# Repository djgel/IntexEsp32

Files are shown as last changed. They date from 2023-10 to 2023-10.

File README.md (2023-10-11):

# Intex® PureSpa ESP32 control Board with Home Automation

**Control your PureSpa over MQTT for 28462, 28458 & 28457, 28561

This  software is user for hardware IntexESP32HW and used with Smart Home (optimized for [Jeedom](www.jeedom.com) & [Home Assistant](https://www.home-assistant.io)).

Codes has partial copy / inspiration of [Yogui79/IntexPureSpa] (https://github.com/Yogui79/IntexPureSpa/blob/main/README.md#hardware-to-you-need)

## Pictures & Videos
-------
- [Video - Home Assistant - Screen Recording ](https://youtu.be/5Z1keongL40)

## Hardware to you need

-   **ESP32 Dev Kit 38Pin**  (Microcontroller) -  [amazon.de](https://amzn.to/3uoa2y4) or [amazon.fr](https://amzn.to/2RvXbLn)]
-   "[**Esp32PureSpa**] (Hardware/)" Board to make! (in Developed)

## Software to you need

-   [**Arduino IDE**](https://www.arduino.cc/en/software)
-   **Install the “[ESP32 Dev Kit C 38pin](https://www.silabs.com/developers/usb-to-uart-bridge-vcp-drivers)” ** (V1 boards not  work)
-   **Install ESP32 Board for  Arduino IDE (verssion 1.0.6)  ->  [Screenshot](Docs/Image/Board-Screenshot-IDE.PNG). **
-   **Install the following libraries**  (use the Arduino Library Manager)
    -   EspMQTTClient
    -   arduino-timer
    -   WiFi (comming with Board Driver in Arduino IDE)
    -   ESPmDNS (comming with Board Driver in Arduino IDE)
    -   ArduinoOTA
-   **You need a MQTT broker**  (e.g. Mosquitto Broker)

## PureSpa Software
Now you can [Download](src/Spa/) the PureSpa code change it to your settings and upload it to your ESP or Arduino

## MQTT communication protocol

**Write your WIFI settings in this lines**

```
const char* Myssid = "YourSSID";
const char* Mypassword = "YourPassword";
```

----------

**Write your MQTT settings in this lines**

```
"YourMQTT-Broker-IP", 	  // MQTT Broker server ip
"NameMQTTBroker",        // Can be omitted if not needed
"PasswordMQTTBroker",   // Can be omitted if not needed
"IntexSpa",            // Client name that uniquely identif your device. Don't change the name!
 1883                 // The MQTT port, default to 1883. this line can be omitted
```

----------

**MQTT topic & payload**

-   Topic is the path to communtions over MQTT:  
    e.g.:  _**IntexSpa/Cmd Power on off**_
-   Payload is the command 

| Description | Topic String | Payload | Payload | Only Status |
|---|---|---|---|---|
| **Power** | IntexSpa/Cmd Power on off | ON=1 | OFF=0 | - |
| **Water Filter** | IntexSpa/Cmd water filter on off | ON=1 | OFF=0 | - |
| **Water Filter Timer** | IntexSpa/Cmd water filter time | hours=2,4,6 | - | - |
| **Bubble** | IntexSpa/Cmd bubble on off | ON=1 | OFF=0 | - |
| **Heater** | IntexSpa/Cmd heater on off | ON=1 | OFF=0 | - |
| **Change Farenheit/Celsius** | IntexSpa/Cmd Farenheit Celsius | F=1 | C=0 | - |
| **Decrease the Temp.** | IntexSpa/Cmd decrease | UP=1 | - | - |
| **Increase the Temp.** | IntexSpa/Cmd increase | Down=1  | - | -  
| **ESP Reset** | IntexSpa/Cmd Reset ESP | reset | - | - |  
| **Command Setpoint of Temp.** | IntexSpa/Cmd Temperature Setpoint| "set a number"  | - | -
| **Heater Status** | IntexSpa/heater state | standby=1 & ON=2  | OFF=0 | Yes
| **Status Setpoint Temp.** | IntexSpa/Temperature Setpoint | - | - | Yes
| **Send Actual Temp 01.** | IntexSpa/Actual Temperature01 | - | - | Yes |
| **Send Actual Temp 02.** | IntexSpa/Actual Temperature02 | - | - | Yes |out
| **Send Actual Flow.** | IntexSpa/Actual Flow | - | - | Yes |
| **Send Error Message** | IntexSpa/Error Number | - | - | Yes |
| **Status Power on** | IntexSpa/Power on | - | - | Yes |  
| **Status Bubble on** | IntexSpa/Bubble on | - | - | Yes |  
| **Status Heater on** | IntexSpa/heater on | - | - | Yes |  
| **Status Filter on** | IntexSpa/filter on | - | - | Yes |
| **Status Filter Timer** | IntexSpa/filter setup time | - | - | Yes | 
| **Water Jet** |  IntexSpa/Cmd water jet on off | ON=1 | OFF=0 | - |
| **Sanitizer** | IntexSpa/Cmd sanitizer on off | ON=1 | OFF=0 | - |
| **Status Water Jet** | IntexSpa/Water jet on | - | - | Yes |
| **Sanitizer Timer** | IntexSpa/Cmd Sanitizer time | hours=3,5,8 | -  | - |
| **Status Sanitizer** | IntexSpa/Sanitizer on | - | - | Yes |
| **Status Sanitizer Timer** | IntexSpa/Sanitizer setup time | - | - | Yes |

## Debugging

You can debug on Arduino IDE with serial print on  **baud rate: 115200**

Options to debug  
_Uncomment to debug_  

	//#define DEBUG_RECIEVED_DATA
	//#define DEBUG_SEARCH_CHANNEL
	//#define DEBUG_SEND_COMMAND
	//#define DEBUG_PUMP_DATA
	//#define DEBUG_CONTROLER_DATA
	//#define DEBUG_CONFIG
	//#define DEBUG_MQTT
	//#define DEBUG_SEND_VALUE_TO_HOME_AUTOMATION_SW

## OTA update

You can use OTA update (wireless) via Arduino IDE after the first upload via USB.  [Screenshot](Docs/Image/Screenshot-OTA.PNG)

## Home Assistant
Is a powerful open source home automation software. [www.home-assistant.io](https://www.home-assistant.io)

You can use it as you want, I'll show you an example of a part of the files configuration.yaml and automations.yaml

**Screenshot & Video:**
1. [OFF - Whrilpool Screenshot](Docs/Image/1.HomeAssistant-OFF_Screenshot.jpg) 
2. [ON - Whrilpool Screenshot](Docs/Image/2.HomeAssistant-ON_Screenshot.jpg)
3. [Help/Infos/Reset Screenshot](Docs/Image/3.HomeAssistant-Help-Infos_Screenshot.jpg)
4. [Heat Timer](Docs/Image/4.HomeAssistant-Timer_Screenshot.jpg)
5. [Push-notification Screenshot](Docs/Image/5.HomeAssistant-Push-notification_Screenshot.jpg)
6. [Video - Screen Recording ](https://youtu.be/5Z1keongL40)

**Config of Home Assistant:** 
- [**configuration.yaml**](src/HomeAutomation/HomeAssistant/configuration.yaml)
   - Define the switches and sensors with MQTT Topics and Payload.

- [**automations.yaml**](src/HomeAutomation/HomeAssistant/automations.yaml) **(optional)**

  - All your automation settings such as push-notification on your mobile phone.

## Jeedom 

Is a powerful and innovative open source home automation software. [www.jeedom.com](https://jeedom.com/)

**Screenshot & Video:**
1. [Screenshot dashboard view](Docs/Image/10.Jeedom-Dashboard.png)
2. [Wiring video](https://www.youtube.com/watch?v=50lxF08o_vo) thanks [@Dim](https://github.com/jeedom-help-Dim-Ant)
3. Configuration video **comming soon**.

**Config of Jeedom:** 

Template for the MQTT topics are available inside the beta version from the jeedom plugin jMQTT

**On jeedom Community thread:** 

you can found some information/help (in french) on the [Jeedom Community thread](https://community.jeedom.com/t/intex-purespa-avec-commande-sans-fils/59334)

## The official Intex® PureSpa instructions

| Articel No. | English  | German |
|---|---|---|
| 28462, 28458 & 28457, 28561 | [Download](Docs/28462-28458_344IO_202_EN_.pdf) | [Download](Docs/28462_28458_344IO_2020_DE.pdf) |

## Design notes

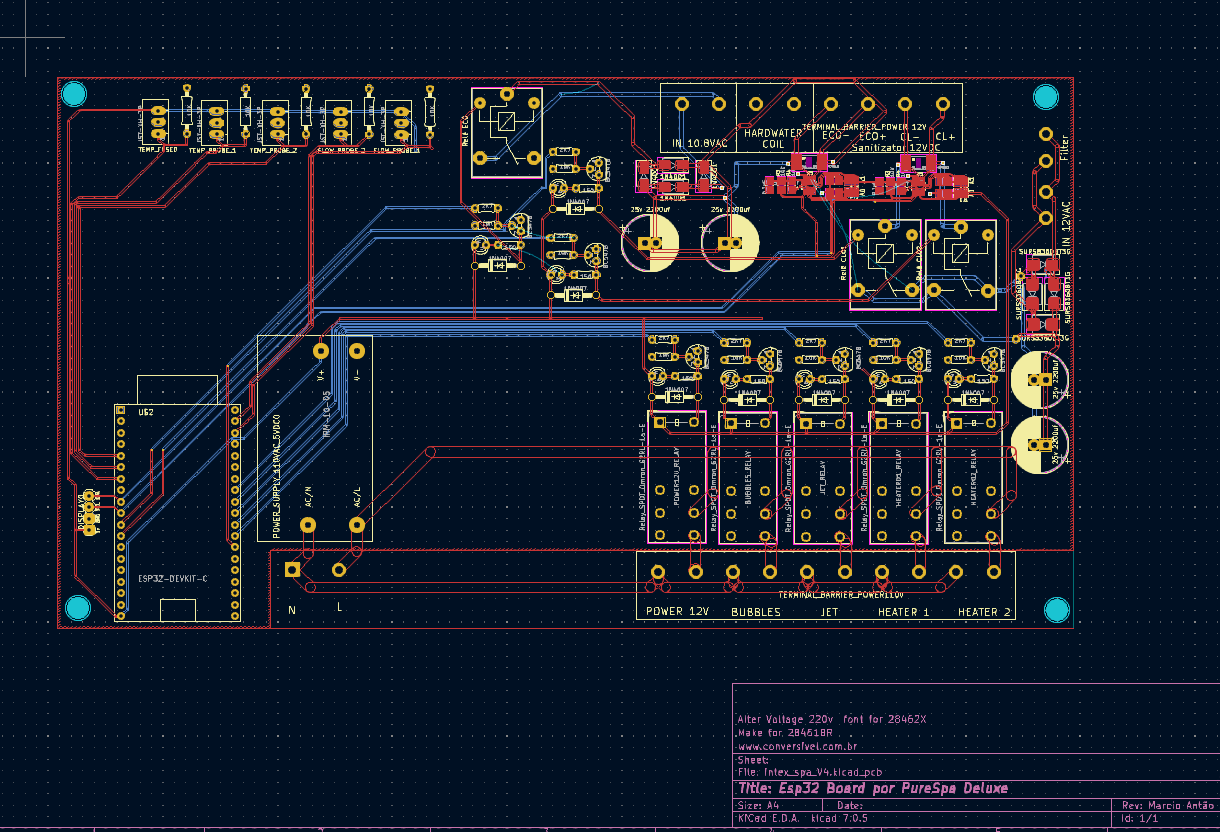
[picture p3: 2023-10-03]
img/BoardKicad.png

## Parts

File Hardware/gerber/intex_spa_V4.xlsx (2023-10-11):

Id | Designador | Footprint | Quantidade | DesignaÃ§Ã£o | Fornecedor e referÃªncia
1 | D8,D13,D15,D14,D9,D10,D11,D12 | DO41-10 | 8 | 1N4007
2 | FLOW_PROBE_2,FLOW_PROBE_1,TEMP_FUSED,TEMP_PROBE_1,TEMP_PROBE_2 | JST-XH-03-PACKAGE-LONG-PAD | 5 | JST-XH-3P
4 | R21,R16,R25,R24,R20,R22,R19,R17 | 805 | 8 | 10K
5 | C4,C1,C3,C2 | CP_Radial_D12.5mm_P2.50mm | 4 | CP_Radial_D12.5mm_P2.50mm
6 | S1 | SW_DIP_SPSTx01_Slide_6.7x4.1mm_W7.62mm_P2.54mm_LowProfile | 1 | SW_DIP_SPSTx01_Slide_6.7x4.1mm_W7.62mm_P2.54mm_LowProfile
7 | U1,U2 | SOT23-8 | 2 | INA219BIDCNT
9 | R34,R11,R31,R28,R25,R37,R14,R8 | 0204_5 | 8 | 10K
10 | D4,D2,D3,D1 | D_SMB | 4 | SURS8360BT3G
11 | RelÃª ECO,RelÃª CL02,RelÃª CL01 | Relay_SPDT_SANYOU_SRD_Series_Form_C | 3 | Relay_SPDT_SANYOU_SRD_Series_Form_C
12 | T_HEATER2_RELAY,T_BUBBLES_RELAY,T_RELAY_CL2,T_PUMP_RELAY0,T__HEATER1_RELAY,T_PUMP_RELAY1,T_RELAY_CL1,T_RELAY_ECO | TO92 | 8 | BC547B
13 | R9,R12,R38,R15,R32,R29,R35,R26 | 0204_5 | 8 | 150
14 | D6,D5,D8,D7 | D_SMA | 4 | 1N4001
15 | R3,R4,R1,R6,R5 | 0207_10 | 5 | 10K
16 | LED_HEATER1_RELAY,LED_RELAY_CL2,LED_RELAY_CL1,LED_HEATER2_RELAY,PUMP0,LED_BUBBLES_RELAY,LED_RELAY_ECO,JET0 | LED3MM | 8
18 | DISPLAY0 | 1X04 | 1 | 4 PINS CONNECTOR
19 | C6,C5 | 805 | 2 | 0.1ÂµF
20 | BUBBLES_RELAY,HEATER02_RELAY,POWER12V_RELAY,HEATER01_RELAY,JET_RELAY | Relay_SPDT_Omron_G2RL-1-E | 5 | Relay_SPDT_Omron_G2RL-1a-E
21 | TERMINAL_BARRIER_POWER 12V | 4PCV-04-006 | 1 | 4PCV-04-006
22 | R30,R10,R27,R36,R7,R33,R13,R24 | 0204_5 | 8 | 2K7
23 | R18,R23 | 2512 | 2 | 0.1/1% (PT2512FK-070R1L)
24 | POWER_SUPPLY_110VAC_5VDC0 | IRM_05_10 | 1 | IRM-10-05
25 | TERMINAL_BARRIER_POWER110v | 4PCV-10-006 | 1 | 4PCV-10-006
26 | TERMINAL_BARRIER_POWER 12V | 4PCV-08-006 | 1 | 4PCV-08-006

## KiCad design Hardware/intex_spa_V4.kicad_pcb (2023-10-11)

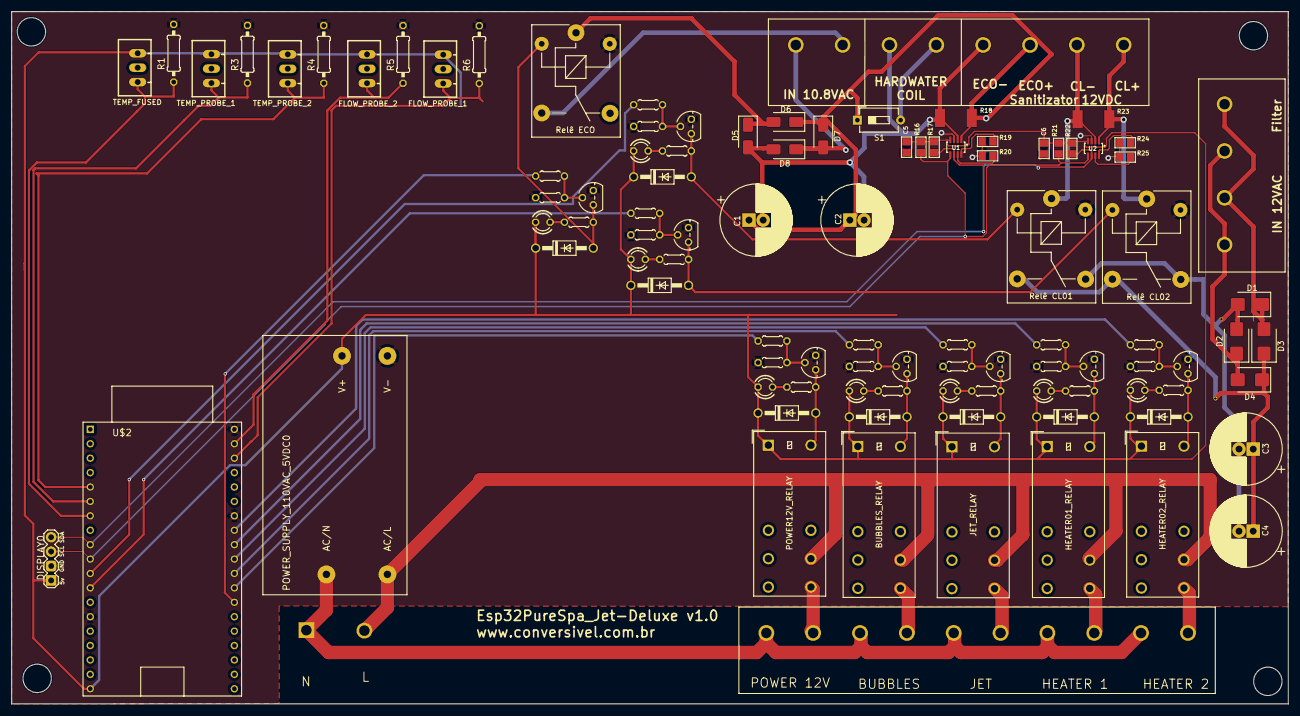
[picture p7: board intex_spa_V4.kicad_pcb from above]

Board: 2 copper layers, 225.0 x 122.0 mm, 103 parts (0 on the bottom side), 59 nets.

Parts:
@HOLE0, @HOLE1, @HOLE2, @HOLE3: (no value)
BUBBLES_RELAY: Relay_SPDT_Omron_G2RL-1a-E; Relay_SPDT_Omron_G2RL-1-E
C1, C2, C3, C4: CP_Radial_D12.5mm_P2.50mm
C5, C6: 0.1µF; 0805
D1, D2, D3, D4: SURS8360BT3G; D_SMB
D5, D6, D7, D8#2: 1N4001; D_SMA
D8, D9, D10, D11, D12, D13, D14, D15: 1N4007; DO41-10
DISPLAY0: 4 PINS CONNECTOR; 1X04
FLOW_PROBE_1, FLOW_PROBE_2: JST-XH-3P; JST-XH-03-PACKAGE-LONG-PAD
HEATER01_RELAY, HEATER02_RELAY: Relay_SPDT_Omron_G2RL-1a-E; Relay_SPDT_Omron_G2RL-1-E
JET0: LED3MM
JET_RELAY: Relay_SPDT_Omron_G2RL-1a-E; Relay_SPDT_Omron_G2RL-1-E
LED1: LED3MM
LED_BUBBLES_RELAY: LED3MM
LED_HEATER1_RELAY, LED_HEATER2_RELAY: LED3MM
LED_RELAY_CL1, LED_RELAY_CL2: LED3MM
POWER12V_RELAY: Relay_SPDT_Omron_G2RL-1a-E; Relay_SPDT_Omron_G2RL-1-E
POWER_SUPPLY_110VAC_5VDC0: IRM-10-05; IRM_05_10
PUMP0: LED3MM
R1, R3, R4, R5, R6: 10K; 0207_10
R7, R10, R13, R24#2, R27, R30, R33, R36: 2K7; 0204_5
R8, R11, R14, R25#2, R28, R31, R34, R37: 10K; 0204_5
R9, R12, R15, R26, R29, R32, R35, R38: 150; 0204_5
R16, R17, R19, R20, R21, R22, R24, R25: 10K; 0805
R18, R23: 0.1/1% (PT2512FK-070R1L); 2512
Relê CL01, Relê CL02: Relay_SPDT_SANYOU_SRD_Series_Form_C
Relê ECO: Relay_SPDT_SANYOU_SRD_Series_Form_C
S1: SW_DIP_SPSTx01_Slide_6.7x4.1mm_W7.62mm_P2.54mm_Lo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; SW_DIP_SPSTx01_Slide_6.7x4.1mm_W7.62mm_P2.54mm_LowProfile
TEMP_FUSED: JST-XH-3P; JST-XH-03-PACKAGE-LONG-PAD
TEMP_PROBE_1, TEMP_PROBE_2: JST-XH-3P; JST-XH-03-PACKAGE-LONG-PAD
TERMINAL_BARRIER_POWER110v: 4PCV-10-006
TERMINAL_BARRIER_POWER 12V: 4PCV-04-006
TERMINAL_BARRIER_POWER 12V#2: 4PCV-08-006
T_BUBBLES_RELAY: BC547B; TO92
T_HEATER2_RELAY: BC547B; TO92
T_PUMP_RELAY0, T_PUMP_RELAY1: BC547B; TO92
T_RELAY_CL1, T_RELAY_CL2: BC547B; TO92
T_RELAY_ECO: BC547B; TO92
T__HEATER1_RELAY: BC547B; TO92
U1, U2: INA219BIDCNT; SOT23-8
U$2: ESP32-DEVKIT-C

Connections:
10.8VAC+: D5.1, D6.2, Relê ECO.1, Relê ECO.3, TERMINAL_BARRIER_POWER 12V#2.I2
10.8VAC_N: D7.2, D8#2.1, TERMINAL_BARRIER_POWER 12V#2.I1
12VAC+: D1.1, D3.2, TERMINAL_BARRIER_POWER 12V.I2, TERMINAL_BARRIER_POWER 12V.I4
12VAC_N: D2.1, D4.2, TERMINAL_BARRIER_POWER 12V.I1, TERMINAL_BARRIER_POWER 12V.I3
12VDC+: C1.1, C2.1, C3.1, C4.1, D3.1, D4.1, D6.1, D7.1, R18.2, Relê CL01.3, Relê CL02.3, S1.1, S1.2, TERMINAL_BARRIER_POWER 12V#2.I4, TERMINAL_BARRIER_POWER 12V#2.I6, U1.1
12VDC-: C1.2, C2.2, C3.2, C4.2, D1.2, D2.2, D5.2, D8#2.2, R18.1, Relê CL01.4, Relê CL02.4, TERMINAL_BARRIER_POWER 12V#2.I3, TERMINAL_BARRIER_POWER 12V#2.I5, U1.2
12VDC_CL: R23.1, R23.2, Relê CL01.1, Relê CL02.1, TERMINAL_BARRIER_POWER 12V#2.I7, TERMINAL_BARRIER_POWER 12V#2.I8, U2.1, U2.2
+5V: BUBBLES_RELAY.A1, C5.1, C6.1, D8.C, D9.C, D10.C, D11.C, D12.C, D13.C, D14.C, D15.C, DISPLAY0.1, FLOW_PROBE_1.3, FLOW_PROBE_2.3, HEATER01_RELAY.A1, HEATER02_RELAY.A1, JET0.A, JET_RELAY.A1, LED1.A, LED_BUBBLES_RELAY.A, LED_HEATER1_RELAY.A, LED_HEATER2_RELAY.A, LED_RELAY_CL1.A, LED_RELAY_CL2.A, POWER12V_RELAY.A1, POWER_SUPPLY_110VAC_5VDC0.V+, PUMP0.A, R16.2, R17.2, R21.2, R22.2, TEMP_FUSED.3, TEMP_PROBE_1.3, TEMP_PROBE_2.3, U1.4, U2.4, U$2.5V
A_BUBBLES: BUBBLES_RELAY.A2, D12.A, R29.2, T_BUBBLES_RELAY.3
A_CL_R01: D9.A, R15.2, Relê CL01.2, T_RELAY_CL1.3
A_CL_R02: D10.A, R12.2, Relê CL02.2, T_RELAY_CL2.3
A_ECO: D8.A, R9.2, Relê ECO.2, T_RELAY_ECO.3
A_HEATER_01: D14.A, HEATER01_RELAY.A2, R35.2, T__HEATER1_RELAY.3
A_HEATER_02: D15.A, HEATER02_RELAY.A2, R38.2, T_HEATER2_RELAY.3
A_JET: D13.A, JET_RELAY.A2, R32.2, T_PUMP_RELAY1.3
A_PUMP: D11.A, POWER12V_RELAY.A2, R26.2, T_PUMP_RELAY0.3
GND: C5.2, C6.2, DISPLAY0.2, POWER_SUPPLY_110VAC_5VDC0.V-, R1.2, R3.2, R4.2, R5.2, R6.2, R8.2, R11.2, R14.2, R19.1, R20.1, R24.1, R25.1, R25#2.2, R28.2, R31.2, R34.2, R37.2, Relê CL01.5, Relê CL02.5, Relê ECO.5, T_BUBBLES_RELAY.1, T_HEATER2_RELAY.1, T_PUMP_RELAY0.1, T_PUMP_RELAY1.1, T_RELAY_CL1.1, T_RELAY_CL2.1, T_RELAY_ECO.1, T__HEATER1_RELAY.1, U1.3, U2.3, U$2.GND, U$2.GND2, U$2.GND3
I1_ELT1: R20.2, U1.7
I1_ELT2: R25.2, U2.7
I2_ELT1: R19.2, U1.8
I2_ELT2: R24.2, U2.8
LEAD: BUBBLES_RELAY.11, HEATER01_RELAY.11, HEATER02_RELAY.11, JET_RELAY.11, POWER12V_RELAY.11, POWER_SUPPLY_110VAC_5VDC0.AC/L
LEAD_BUBBLES: BUBBLES_RELAY.14, TERMINAL_BARRIER_POWER110v.I4
LEAD_HEATER_1: HEATER01_RELAY.14, TERMINAL_BARRIER_POWER110v.I8
LEAD_HEATER_2: HEATER02_RELAY.14, TERMINAL_BARRIER_POWER110v.I10
LEAD_JET: JET_RELAY.14, TERMINAL_BARRIER_POWER110v.I6
LEAD_PUMP: POWER12V_RELAY.14, TERMINAL_BARRIER_POWER110v.I2
unnamed: PUMP0.K, R26.1
unnamed: JET0.K, R32.1
unnamed: LED_HEATER1_RELAY.K, R35.1
unnamed: LED_HEATER2_RELAY.K, R38.1
unnamed: R36.1, R37.1, T_HEATER2_RELAY.2
unnamed: R33.1, R34.1, T__HEATER1_RELAY.2
unnamed: R27.1, R28.1, T_BUBBLES_RELAY.2
unnamed: R30.1, R31.1, T_PUMP_RELAY1.2
unnamed: R10.1, R11.1, T_RELAY_CL2.2
unnamed: LED_RELAY_CL2.K, R12.1
unnamed: LED1.K, R9.1
unnamed: R7.1, R8.1, T_RELAY_ECO.2
unnamed: LED_RELAY_CL1.K, R15.1
unnamed: R13.1, R14.1, T_RELAY_CL1.2
unnamed: LED_BUBBLES_RELAY.K, R29.1
unnamed: R24#2.1, R25#2.1, T_PUMP_RELAY0.2
NEUTRAL: POWER_SUPPLY_110VAC_5VDC0.AC/N, TERMINAL_BARRIER_POWER110v.I1, TERMINAL_BARRIER_POWER110v.I3, TERMINAL_BARRIER_POWER110v.I5, TERMINAL_BARRIER_POWER110v.I7, TERMINAL_BARRIER_POWER110v.I9
SCL: DISPLAY0.3, R16.1, R21.1, U1.5, U2.5, U$2.IO26
SDA: DISPLAY0.4, R17.1, R22.1, U1.6, U2.6, U$2.IO25
SENSOR_FPROBE01: FLOW_PROBE_1.1, R6.1, U$2.IO22
SENSOR_FPROBE02: FLOW_PROBE_2.1, R5.1, U$2.IO23
SENSOR_TFUSE: R1.1, TEMP_FUSED.1, U$2.IO32
SENSOR_TPROBE01: R3.1, TEMP_PROBE_1.1, U$2.IO35
SENSOR_TPROBE02: R4.1, TEMP_PROBE_2.1, U$2.IO34
S_BUBBLES: R27.2, U$2.IO17
S_CL_R01: R13.2, U$2.IO27
S_CL_R02: R10.2, U$2.IO14
S_ECO: R7.2, U$2.IO4
S_HEATER_1: R33.2, U$2.IO18
S_HEATER_2: R36.2, U$2.IO19
S_JET: R30.2, U$2.IO5
S_PUMP: R24#2.2, U$2.IO16

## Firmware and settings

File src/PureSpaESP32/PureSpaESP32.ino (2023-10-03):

/*
 *
 * Intex Purespa Esp32 Board Controler 
 * 
 *
 * THIS SOFTWARE IS PROVIDED "AS IS" AND
 * ANY EXPRESS OR IMPLIED WARRANTIES, INCLUDING, BUT NOT LIMITED TO, THE IMPLIED
 * WARRANTIES OF MERCHANTABILITY AND FITNESS FOR A PARTICULAR PURPOSE ARE
 * DISCLAIMED. IN NO EVENT SHALL <COPYRIGHT HOLDER> BE LIABLE FOR ANY
 * DIRECT, INDIRECT, INCIDENTAL, SPECIAL, EXEMPLARY, OR CONSEQUENTIAL DAMAGES 
 * (INCLUDING, BUT NOT LIMITED TO, PROCUREMENT OF SUBSTITUTE GOODS OR SERVICES;
 * LOSS OF USE, DATA, OR PROFITS; OR BUSINESS INTERRUPTION) HOWEVER CAUSED AND
 * ON ANY THEORY OF LIABILITY, WHETHER IN CONTRACT, STRICT LIABILITY, OR TORT
 * (INCLUDING NEGLIGENCE OR OTHERWISE) ARISING IN ANY WAY OUT OF THE USE OF THIS
 * SOFTWARE, EVEN IF ADVISED OF THE POSSIBILITY OF SUCH DAMAGE.
 *

*/

//Now Only  work to Jet&bubbles Delux




/*******************************************************
*
*   S E L E C T  T H E   P R O T O C O L   Y O U   U S E
*  
********************************************************/
//#define _MY_SENSORS_
#define _MQTT_

#ifdef ESP32
const char* Myssid = "MeMs";
const char* Mypassword = "1475963m";
#endif


#if defined (_MY_SENSORS_) &&  defined (_MQTT_)
   #error select between mysensors and MQTT 
#endif

#ifdef _MQTT_
#include "EspMQTTClient.h"

EspMQTTClient client(
  Myssid,
  Mypassword,
  "192.168.31.200",  // MQTT Broker server ip
  "MeMsCasa",   // Can be omitted if not needed
  "",   // Can be omitted if not needed
  "IntexSpa",     // Client name that uniquely identify your device
  1883              // The MQTT port, default to 1883. this line can be omitted
);
#endif

//Uncomment following line to have more debug infos
//#define DEBUG_RECIEVED_DATA
//#define DEBUG_SEARCH_CHANNEL
//#define DEBUG_SEND_COMMAND
//#define DEBUG_PUMP_DATA
//#define DEBUG_CONTROLLER_DATA
//#define DEBUG_CONFIG
//#define DEBUG_MQTT
//#define DEBUG_SEND_VALUE_TO_HOME_AUTOMATION_SW

bool FirstSend;

#include <arduino-timer.h>

#define mySerial   Serial2
#define DO_SET    19
#define DO_CS     18



// PINs
#define PUMP_PIN       16
#define BUBBLES_PIN    17
#define JET_PIN        5
#define HEATER01_PIN   18
#define HEATER02_PIN   19
#define CL01_PIN       27
#define CL02_PIN       14
#define ECO_PIN        4
#define TEMP01_PIN     35
#define TEMP02_PIN     34
#define FLOW01_PIN     22
#define FLOW02_PIN     23
#define TFUSE_PIN      32
#define SDA_PIN        25
#define SCL_PIN        26


#include <WiFi.h>
#include <ESPmDNS.h>
#include <WiFiUdp.h>
#include <ArduinoOTA.h>
#include <Wire.h>
#include <Adafruit_INA219.h>


//Amp Modulo INA219

Adafruit_INA219 ina219_0 (0x40);
Adafruit_INA219 ina219_1 (0x41);

//Version and date
#define _VERSION         "1.0"
#define _BUILD_DATE_TIME "2023.10.03 "


//Command
#define COMMAND_ON_OFF                0x0001    
#define COMMAND_WATER_FILTER          0x0010    
#define COMMAND_BUBBLE                0x0020    
#define COMMAND_HEATER                0x0040    
#define COMMAND_CELSIUS_FARENHEIT     0x0002    
#define COMMAND_DECREASE              0x0008    
#define COMMAND_INCREASE              0x0004    
#define COMMAND_WATER_JET             0x0100    
#define COMMAND_SANITIZER             0x0080    

// Status Byte number
#define BYTE_STATUS_STATUS            2
#define BYTE_STATUS_COMMAND           4

#define BYTE_ACTUAL_TEMPERATURE       5
#define BYTE_SETPOINT_TEMPERATURE     7

#define BYTE_SETPOINT_TIME_SANITIZER  8

#define BYTE_SETPOINT_TIME_FILTER     12

#define BYTE_ERROR                    14

//Value Pump bytes
#define VALUE_CONTROLLER_ON           0x01
#define VALUE_BUBBLE_ON               0x10

#define VALUE_HEATER_STANDBY          0x02
#define VALUE_HEATER_ON               0x04  
#define VALUE_WATER_FILTER_ON         0x08  

#define VALUE_WATER_JET_ON            0x80  
#define VALUE_SANITIZER_ON            0x20  


#define VALUE_FARENHEIT               0x01
#define VALUE_TEMP_WINDOWS_OPEN       0x02
#define VALUE_COMMAND_RECIVED         0x80

// Commande bytes
#define BYTE_CONTROLLER_LOADING        3

// Value Controller bytes

//varibles for datamanagement
#define SIZE_CONTROLLER_DATA         8
unsigned char DataController[SIZE_CONTROLLER_DATA +2];

//Id for mysensors and for memo
uint16_t MemValueSended[40];

#define ID_POWER_ON                 1
#define ID_BUBBLE_ON                2
#define ID_HEATER_ON                3
#define ID_HEATER_STATE             4
#define ID_WATER_FILTER_ON          5
#define ID_WATER_FILTER_TIME        6
#define ID_VALUE_WATER_JET_ON       7
#define ID_SANITIZER_ON             8
#define ID_SANITIZER_TIME           9

#define ID_FARENHEIT                15

#define ID_SETPOINT_TEMPERATURE     20
#define ID_ACTUAL_TEMPERATURE       21
#define ID_TARGET_TEMPERATURE       22
#define ID_TARGET_FILTER_TIME       23
#define ID_TARGET_SANITIZER_TIME    24

#define ID_ERROR_CODE               35
#define ID_COM_PUMP                 36

#define SIZE_PUMP_DATA               17
unsigned char Data[SIZE_PUMP_DATA +2];
uint16_t DataCounter=0;

//internal variables
auto t = timer_create_default(); // create a timer with default settings
bool FinishPumpMessage;
bool FinishControllerMessage;
char ControllerLoadingState;
uint16_t state;
uint16_t CommandToSend =0x0000;
bool CommandRecived;
long LastTimeReciveData;
bool ErrorCommunicationWithPump;
long LastTimeSendData;
long LastTimeReciveDataCheckChannel;
uint8_t ActualSearchChannel;
uint16_t SearchChannelDataCount; 
uint8_t UsedChannel;
uint8_t FirstCommandChar;
uint16_t ChannelChangeOk;
bool FarenheitCelsius;
uint8_t ActualSetpointTemperarue;
uint8_t TargetSetpointTemperarue;
bool ChangeTargetSetpointTemperarue;
bool ChangeSetpointRecirculationTime;
uint8_t ActualSetpointRecirculationTime;
uint8_t TargetSetpointRecirculationTime;
bool SwitchOffRecirculation;
bool StateRecirculation;
bool ChangeSetpointSanitizerTime;
uint8_t ActualSetpointSanitizerTime;
uint8_t TargetSetpointSanitizerTime;
bool SwitchOffSanitizer;
bool StateSanitizer;


//Setup
void setup() {
 
  mySerial.begin(9600);
  Serial.begin(115200);

  Serial.println(F("----------------------------------------------------------------------------------------------------------------------")); 
  Serial.println(F(""));
  Serial.print (F("          Intex Purespa communication sketch version "));  
  Serial.print (_VERSION);
  Serial.print (F(" build on : "));
  Serial.println (_BUILD_DATE_TIME);  
  Serial.println(F(""));
  Serial.println(F("----------------------------------------------------------------------------------------------------------------------"));  
  

  Serial.println("Booting");
  WiFi.mode(WIFI_STA);
  WiFi.begin(Myssid, Mypassword);
  while (WiFi.waitForConnectResult() != WL_CONNECTED) {
    Serial.println("Connection Failed! Rebooting...");
    delay(5000);
    ESP.restart();
  }

  ArduinoOTA
    .onStart([]() {
      String type;
      if (ArduinoOTA.getCommand() == U_FLASH)
        type = "sketch";
      else // U_SPIFFS
        type = "filesystem";

      // NOTE: if updating SPIFFS this would be the place to unmount SPIFFS using SPIFFS.end()
      Serial.println("Start updating " + type);
    })
    .onEnd([]() {
      Serial.println("\nEnd");
    })
    .onProgress([](unsigned int progress, unsigned int total) {
      Serial.printf("Progress: %u%%\r", (progress / (total / 100)));
    })
    .onError([](ota_error_t error) {
      Serial.printf("Error[%u]: ", error);
      if (error == OTA_AUTH_ERROR) Serial.println("Auth Failed");
      else if (error == OTA_BEGIN_ERROR) Serial.println("Begin Failed");
      else if (error == OTA_CONNECT_ERROR) Serial.println("Connect Failed");
      else if (error == OTA_RECEIVE_ERROR) Serial.println("Receive Failed");
      else if (error == OTA_END_ERROR) Serial.println("End Failed");
    });

  ArduinoOTA.begin();

  Serial.println("Ready");
  Serial.print("IP address: ");
  Serial.println(WiFi.localIP());
  

  
#if  defined (_MQTT_) &&  defined (DEBUG_MQTT)
  client.enableDebuggingMessages(); // Enable debugging messages sent to serial output
#endif  

  delay(1000);
  
  digitalWrite(DO_CS, LOW);     
  digitalWrite(DO_SET, LOW);
  delay(100);

  //read channel inside EERPOM 
  t.every(1600, SendLifeFct);
  LastTimeReciveData = LastTimeSendData= millis();
}// void setup()

void loop() {
   //update timer
   t.tick();


  ArduinoOTA.handle();

   
   if (!FinishPumpMessage)
   {
    {
       if (mySerial.available() ) 
       {
        unsigned char c = mySerial.read();
        ReadData(c);
       }
     }
   }

   //Manage pump message
   if (FinishPumpMessage)
   {
     LastTimeReciveData = millis();
 #ifdef _MQTT_ 
     if (client.isConnected())
 #endif
     {
       DataManagement();
       SendCommandManagement (&CommandToSend);
       SendTemperatureSetpoint();
       SendSpecialCommand(COMMAND_WATER_FILTER, &ChangeSetpointRecirculationTime, SwitchOffRecirculation,TargetSetpointRecirculationTime, ActualSetpointRecirculationTime);
       SendSpecialCommand(COMMAND_SANITIZER, &ChangeSetpointSanitizerTime, SwitchOffSanitizer,TargetSetpointSanitizerTime, ActualSetpointSanitizerTime);
       state =0;
       FirstSend = true;
       FinishPumpMessage = false;  
     }
     
   }
  
   //Manage Controller message
   if (FinishControllerMessage)
   {
#ifdef DEBUG_CONTROLLER_DATA
    Serial.print("Debug Controller data : ");
    char res2[5]; 
    for (uint8_t i =0; i<SIZE_CONTROLLER_DATA;i++){
      sprintf(&res2[0],"%02X",DataController[i]);
      Serial.print(res2);
      Serial.print(" ");
    }
    Serial.println(" ");
#endif    
      ControllerLoadingState = DataController[BYTE_CONTROLLER_LOADING];
      FinishControllerMessage = false;
   }

  client.loop();
  if (   !client.isConnected()
      && !FirstSend 
     ){
      LastTimeReciveData = millis();
     }

  // check communication pump timeout

    {  
      if (millis() - LastTimeReciveData > 5000)
        {
        SendValue("IntexSpa/Communication with pump", false,ID_COM_PUMP); 
        ErrorCommunicationWithPump = true;     
      }
      else{
        SendValue("IntexSpa/Communication with pump", true,ID_COM_PUMP); 
        ErrorCommunicationWithPump = false;
      }
    }
  //Try to find the new channel in case of pump change channel
  if (   !FirstSend 
      &&  (millis() - LastTimeReciveData > 6000 )

      &&  client.isConnected()      

     ){
     if (ChannelChangeOk == 1){ 
        ActualSearchChannel =UsedChannel+1;
     }

     else{
        ActualSearchChannel =UsedChannel -10;
     }
     UsedChannel=0;
     ChannelChangeOk = 0;
     Serial.println (F("Look like channel change since last boot"));
     client.publish("IntexSpa/Notification", "Search the device"); 
     while (!UsedChannel &&  (millis() - LastTimeReciveData < 420000 ))
       SearchChannel();
     if (UsedChannel)
      client.publish("IntexSpa/Notification", "Device found"); 
    }

} //void loop() 

//Managed data recived from the LC12s
void ReadData (unsigned char c)
{ 
   switch (state) 
   {
      case 0: //wait header
      {
        DataCounter=0;
        memset (&Data,0,sizeof(Data));
        memset (&DataController,0,sizeof(DataController));
        
        if (c == FirstCommandChar)
        {
          Data[DataCounter] =c;
          DataCounter++;
          state++;
        }
        break;
      }
      //wait all other data
      case 1:
      {
        Data[DataCounter] =c;
        DataCounter++;

        //it was a message from controller
        if (c == FirstCommandChar && DataCounter< SIZE_PUMP_DATA  && DataCounter > SIZE_CONTROLLER_DATA )
        {     
          memcpy (&DataController,&Data, 8);          
          //Calclulate an check Checksum
          uint16_t crc_out = calc_crc((char*) DataController,SIZE_CONTROLLER_DATA -2);      
          //Checksum ok
          if (   (Data[SIZE_CONTROLLER_DATA-2] == ((crc_out & 0xFF00) >> 8 ))
              && (Data[SIZE_CONTROLLER_DATA-1] == (crc_out & 0x00FF))
             )    
          {
            FinishControllerMessage = true;
          }          
          else
          {
            FinishControllerMessage = false;
          }
         
          DataCounter = 0;
          Data[DataCounter] =c;
          DataCounter++;
        }
        // wait until full pump message is recived
        if (DataCounter> SIZE_PUMP_DATA-1)
        {
          //Calclulate an check Checksum
          uint16_t crc_out = calc_crc((char*)Data,SIZE_PUMP_DATA -2);      
          //Checksum ok
          if (   (Data[SIZE_PUMP_DATA-2] == ((crc_out & 0xFF00) >> 8 ))
              && (Data[SIZE_PUMP_DATA-1] == (crc_out & 0x00FF))
             )    
          {
            state =0;
            FinishPumpMessage = true;
          }
          else{ // Wrong Cheksum
            state =0;
          }         
        }
        break;
      }
   }
}  

//manage information comming from the home automation sofware over MQTT
#ifdef _MQTT_
void onConnectionEstablished()
{
   //manage command power on/off
    client.subscribe("IntexSpa/Cmd Power on off", [](const String & payload) {
      if (payload== "1" || payload== "0"){
        CommandToSend |= COMMAND_ON_OFF ;
        LastTimeSendData = millis();
      }
    });

    //Target Filter time
    client.subscribe("IntexSpa/Cmd water filter time", [](const String & payload) {
      if( (payload== "2" || payload == "4" || payload == "6") ){
        ChangeSetpointRecirculationTime =  StateRecirculation;
        TargetSetpointRecirculationTime = payload.toInt();
             
      }
    });

   //manage command water filter on/off
   client.subscribe("IntexSpa/Cmd water filter on off", [](const String & payload) { 
   if (payload== "1" && (TargetSetpointRecirculationTime== 2 || TargetSetpointRecirculationTime == 4 || TargetSetpointRecirculationTime == 6)){
      ChangeSetpointRecirculationTime = true;
      SwitchOffRecirculation = false;
    }
    else if(payload== "0"){
      ChangeSetpointRecirculationTime = true;
      SwitchOffRecirculation = true;
    }
  });

   //manage command Bubble on/off
   client.subscribe("IntexSpa/Cmd bubble on off", [](const String & payload) {
    if (payload== "1" || payload== "0"){
      CommandToSend |= COMMAND_BUBBLE;
      LastTimeSendData = millis();
    }
  });

   //manage command heater on/off
   client.subscribe("IntexSpa/Cmd heater on off", [](const String & payload) {
    if (payload== "1" || payload== "0"){
    CommandToSend |= COMMAND_HEATER;
      LastTimeSendData = millis();
    }    
  });  

   //manage command Farenheit/Celsius
   client.subscribe("IntexSpa/Cmd Farenheit Celsius", [](const String & payload) {
    if (payload== "1" || payload== "0"){
      CommandToSend |= COMMAND_CELSIUS_FARENHEIT;
      LastTimeSendData = millis();
    }      
  }); 
    
   //manage command decrease
   client.subscribe("IntexSpa/Cmd decrease", [](const String & payload) {
    if (payload== "1")
   {
      LastTimeSendData = millis();
      TargetSetpointTemperarue = TargetSetpointTemperarue -1;
      ChangeTargetSetpointTemperarue = true;     
    }
  }); 

   //manage command increase
   client.subscribe("IntexSpa/Cmd increase", [](const String & payload) {
    if (payload== "1"){
      LastTimeSendData = millis();
      TargetSetpointTemperarue = TargetSetpointTemperarue +1;
      ChangeTargetSetpointTemperarue = true;
    }
  });   

   //manage command temperature setpoint
   client.subscribe("IntexSpa/Cmd Temperature Setpoint", [](const String & payload) {
    TargetSetpointTemperarue = payload.toInt();
    ChangeTargetSetpointTemperarue = true;
  }); 

   // reset
   client.subscribe("IntexSpa/Cmd Reset ESP", [](const String & payload) {
    if (payload== "reset"){
      ESP.restart();
    }
  });   


   //manage command water jet on off
   client.subscribe("IntexSpa/Cmd water jet on off", [](const String & payload) {
    if (payload== "1" || payload== "0"){
      CommandToSend |= COMMAND_WATER_JET;
      LastTimeSendData = millis();
    }
   });   

    //Target Sanitizer time
   client.subscribe("IntexSpa/Cmd Sanitizer time", [](const String & payload) {
      if( (payload== "3" || payload == "5" || payload == "8") ){
        ChangeSetpointSanitizerTime =  StateSanitizer;
        TargetSetpointSanitizerTime = payload.toInt();            
      }
    });

   //manage command sanitizer on/off
   client.subscribe("IntexSpa/Cmd sanitizer on off", [](const String & payload) { 
   if (payload== "1" && (TargetSetpointSanitizerTime== 3 || TargetSetpointSanitizerTime == 5 || TargetSetpointSanitizerTime == 8)){
      ChangeSetpointSanitizerTime = true;
      SwitchOffSanitizer = false;
    }
    else if(payload== "0"){
      ChangeSetpointSanitizerTime = true;
      SwitchOffSanitizer = true;
    }
  });


  
}
#endif

// manage the data recived from the pump and send it to the home autmation software over MQTT
void DataManagement (){
#ifdef DEBUG_PUMP_DATA
    char res[5]; 
    Serial.print("Debug Pump data : ");    
    for (uint8_t i =0; i<SIZE_PUMP_DATA;i++){
      sprintf(&res[0],"%02X",Data[i]);
      Serial.print(res);
      Serial.print(" ");
    }
    Serial.println(" ");
#endif

   // Send power on
   SendValue("IntexSpa/Power on", (bool)(Data[BYTE_STATUS_COMMAND] & VALUE_CONTROLLER_ON),ID_POWER_ON); 

   //Send Bubble on 
   SendValue("IntexSpa/Bubble on", (bool)(Data[BYTE_STATUS_COMMAND] & VALUE_BUBBLE_ON),ID_BUBBLE_ON); 

   //Send heater on 
   SendValue("IntexSpa/heater on", (bool)((Data[BYTE_STATUS_COMMAND] & VALUE_HEATER_ON) || (Data[BYTE_STATUS_COMMAND] & VALUE_HEATER_STANDBY)),ID_HEATER_ON); 

   //Send heater State
   uint16_t HeaterState= 0;
   if (Data[BYTE_STATUS_COMMAND] & VALUE_HEATER_STANDBY){
      HeaterState = 1;      // state standby
   }else if ((Data[BYTE_STATUS_COMMAND] & VALUE_HEATER_ON) ){
     HeaterState = 2;       // state heater on
   }
   SendValue("IntexSpa/heater state", HeaterState ,ID_HEATER_STATE); 

   //Send water filter on 
   StateRecirculation =(bool)(Data[BYTE_STATUS_COMMAND] & VALUE_WATER_FILTER_ON);
   SendValue("IntexSpa/filter on", (bool)(Data[BYTE_STATUS_COMMAND] & VALUE_WATER_FILTER_ON),ID_WATER_FILTER_ON); 

   //Send actual filter setup time
   ActualSetpointRecirculationTime = Data[BYTE_SETPOINT_TIME_FILTER];
   SendValue("IntexSpa/filter setup time", Data[BYTE_SETPOINT_TIME_FILTER],ID_WATER_FILTER_TIME); 
   if (!ChangeSetpointRecirculationTime && ActualSetpointRecirculationTime)
   {
       TargetSetpointRecirculationTime =ActualSetpointRecirculationTime;
       SendValue("IntexSpa/Cmd water filter time", Data[BYTE_SETPOINT_TIME_FILTER],ID_TARGET_FILTER_TIME);   
   }

   //Send water jet on 
   SendValue("IntexSpa/Water jet on", (bool)(Data[BYTE_STATUS_COMMAND] & VALUE_WATER_JET_ON),ID_VALUE_WATER_JET_ON); 

  //Send water sanitizer on 
   StateSanitizer =(bool)(Data[BYTE_STATUS_COMMAND] & VALUE_SANITIZER_ON);
   SendValue("IntexSpa/Sanitizer on", (bool)(Data[BYTE_STATUS_COMMAND] & VALUE_SANITIZER_ON),ID_SANITIZER_ON); 

   //Send actual filter setup time
   ActualSetpointSanitizerTime = Data[BYTE_SETPOINT_TIME_SANITIZER];
   SendValue("IntexSpa/Sanitizer setup time", Data[BYTE_SETPOINT_TIME_SANITIZER],ID_SANITIZER_TIME); 
   if (!ChangeSetpointSanitizerTime && ActualSetpointSanitizerTime)
   {
       TargetSetpointSanitizerTime =ActualSetpointSanitizerTime;
       SendValue("IntexSpa/Cmd Sanitizer time", Data[BYTE_SETPOINT_TIME_SANITIZER],ID_TARGET_SANITIZER_TIME);   
   }  
  
   
   //Send Farenheit selected
   FarenheitCelsius = (bool)(Data[BYTE_STATUS_STATUS] & VALUE_FARENHEIT);
   SendValue("IntexSpa/Farenheit Celsius", (bool)(Data[BYTE_STATUS_STATUS] & VALUE_FARENHEIT),ID_FARENHEIT); 

   //Send temperature setpoint
   ActualSetpointTemperarue = Data[BYTE_SETPOINT_TEMPERATURE];
   SendValue("IntexSpa/Temperature Setpoint", Data[BYTE_SETPOINT_TEMPERATURE],ID_SETPOINT_TEMPERATURE); 
   if (!ChangeTargetSetpointTemperarue)
   {
       TargetSetpointTemperarue =ActualSetpointTemperarue;
       SendValue("IntexSpa/Cmd Temperature Setpoint", Data[BYTE_SETPOINT_TEMPERATURE],ID_TARGET_TEMPERATURE);   
   }

   //Send actual temperature
   SendValue("IntexSpa/Actual Temperature", Data[BYTE_ACTUAL_TEMPERATURE],ID_ACTUAL_TEMPERATURE); 

  //send Error number
   SendValue("IntexSpa/Error Number", Data[BYTE_ERROR],ID_ERROR_CODE); 

  //Manage Command recived
  if (Data[BYTE_STATUS_STATUS] & VALUE_COMMAND_RECIVED){
    CommandRecived = true;
  }
  else{
    CommandRecived = false;
  }
}

//manage send temperature to pump
void SendTemperatureSetpoint(){
  
  //nothing to do 
  if (!ChangeTargetSetpointTemperarue)
    return;
    
  // command is pendling actualy nothing else to do   
  if (    (CommandToSend & COMMAND_INCREASE)
      ||  (CommandToSend & COMMAND_DECREASE)
     )
    return;
    
  // setpoint is done  
  if (    TargetSetpointTemperarue == ActualSetpointTemperarue
      ||  (TargetSetpointTemperarue > 40  && !FarenheitCelsius)
      ||  (TargetSetpointTemperarue < 10  && !FarenheitCelsius)
      ||  (TargetSetpointTemperarue > 50  &&  FarenheitCelsius)
      ||  (TargetSetpointTemperarue < 104 &&  FarenheitCelsius)
     ){
    ChangeTargetSetpointTemperarue   = false;
    return;
  }
    
  //temperature need to be increased -> send increase command
  if (TargetSetpointTemperarue > ActualSetpointTemperarue)
  {
      LastTimeSendData = millis();
      CommandToSend |= COMMAND_INCREASE;
  }

  //temperature need to be decreased -> send decrease command
  if (TargetSetpointTemperarue < ActualSetpointTemperarue)
  {
      LastTimeSendData = millis();
      CommandToSend |= COMMAND_DECREASE;
  }
}
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

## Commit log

2023-10-03 Adiciona o Hardware e limpeza do codigo copiado
    [intex_spa_V4.kicad_pcb]
2023-10-11 Final HW Hardware
    [intex_spa_V4-B_Cu.gbr, intex_spa_V4-B_Mask.gbr, intex_spa_V4-B_Paste.gbr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]
